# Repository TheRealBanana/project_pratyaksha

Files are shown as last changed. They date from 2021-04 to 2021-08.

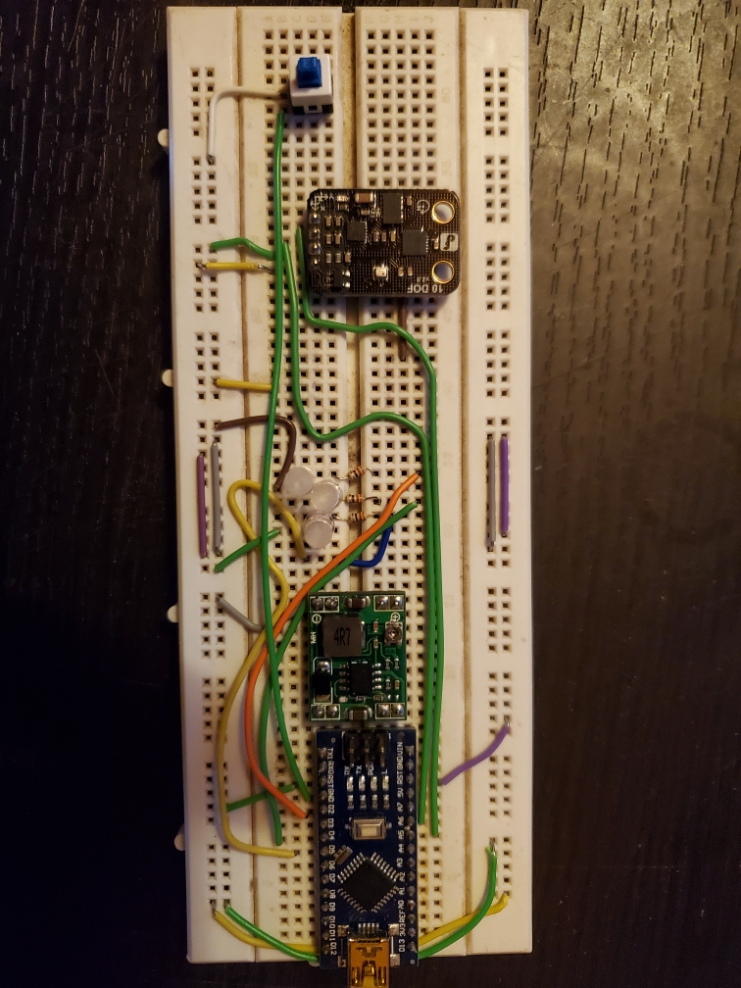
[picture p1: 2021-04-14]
testing_10dof_mems_sensor/breadboard_layout.jpeg

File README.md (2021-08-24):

# Project Pratyaksha
 Extra sensory perception via tactile stimulation

I was inspired by biohackers who have changed the sensory inputs their brains were receiving, showing that the brain can adapt quite well. Bicycles that turn the opposite way of the handlebars, glasses that enable you to see backwards, magnets under the finger to detect EM fields, and more. I wondered what it would be like to add some extra sense. How quickly would the brain learn to use the new information or would it just ignore the data as noise? 

The first idea I had was a simple navigation aid. A belt with 6 vibrating motors around the circumference that always vibrates in the direction of north, adding magnetoreception to our senses. There are many practical applications from helping seeing impaired individuals to a navigation aid for hikers. There's also no constraint as to the source of data being input. We could attach a software defined radio and instead buzz in the direction of certain radio signals. You could have a drone with object recognition inputting data as to the relative location of other people around you. Such a system would give an individual a real-life "spidy-sense".

It will be an interesting experiement. As of the creation of the repo its been under development for a little while (approx around the start of SensorMonitor repo) and I decided to track the progress on github.

--

May 2021 update

Here's what the first complete prototype system looks like. The belt is made from velcro material with the "buckles" self-designed and printed. Each "buckle" has a small 10mm diameter DC cellphone vibration motor glued into a matching recess. The leads from all 6 motors and a ground wire are routed out each end of the belt in 3-wire and 4-wire bundles. Each wire bundle is terminated at its end with a 6-pin header block. The main brainbox contains a custom subboard and a small atmel atmega2560 based prototyping board. The belt plugs into the subboard while the atmel controls everything. The magnetic heading data is taken from the SEN0140 10 degree-of-freedom sensor package. The magnetic heading data is corrected for tilt using the on-board IMU. The placement of the SEN0140 sensor is still undecided so its on a long lead. 

pratyaksha_belt-fullsystem_prototype_1

Aug 2021 update
Turns out not knowing anything about designing circuit boards came back to bite me. My current design has overcurrent issues burning traces out. I needed to add a current limiting resistor to the motor outputs (not sure why I didnt) and maybe thicker traces. Taking a break from the project for a while to concentrate on a laser projector I'm trying to design.

A pic of the v2 board that didn't work right:
pratyaksha_belt-pcb-v2

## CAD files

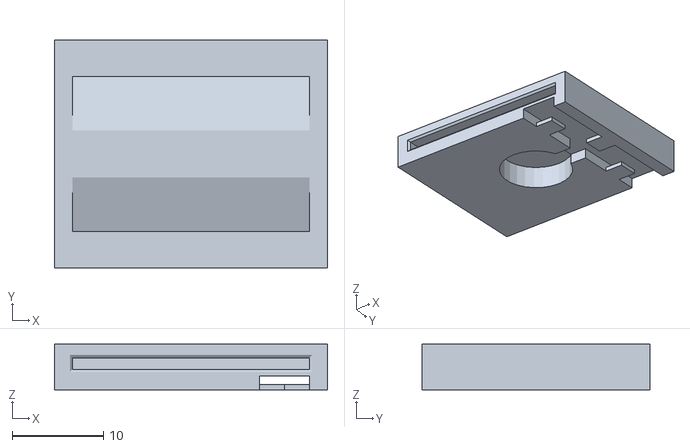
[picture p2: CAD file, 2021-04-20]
CAD Files/body_interface_pad/body_interface_pad_type2_mk1.stl
30.0 x 25.0 x 5.00

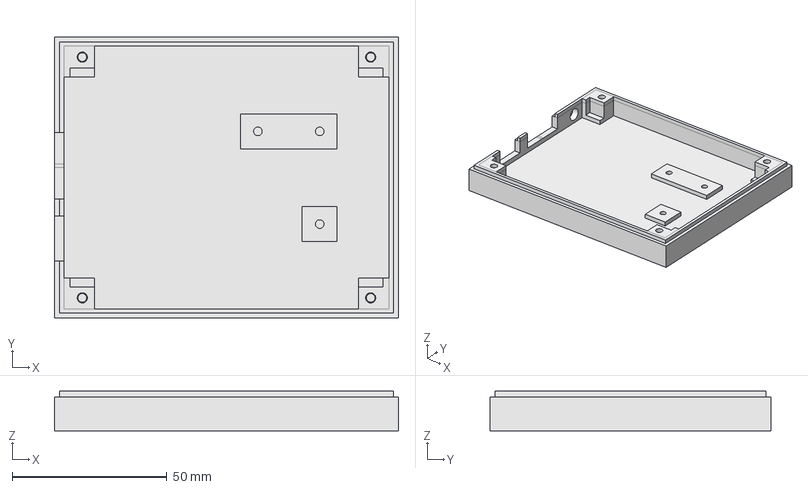
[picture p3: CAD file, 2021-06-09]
CAD Files/brainbox/brainbox_type2.FCStd
111.3 x 91.0 x 12.8 mm

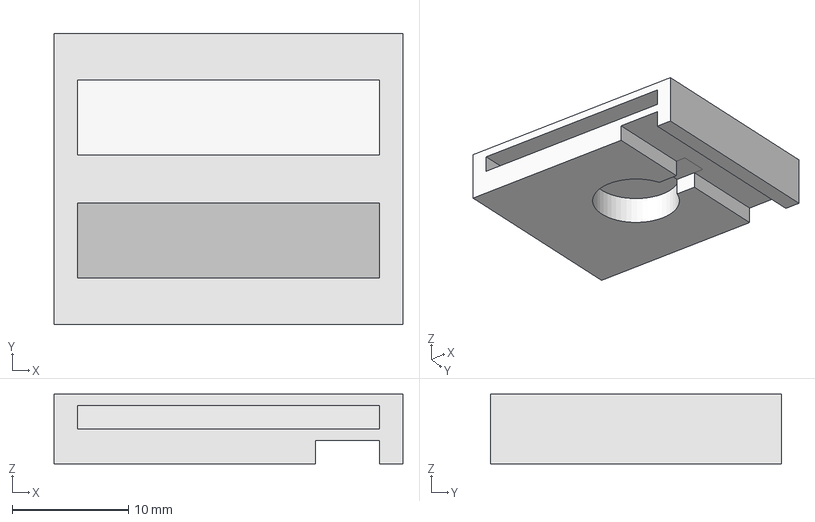
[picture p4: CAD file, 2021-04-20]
CAD Files/body_interface_pad/body_interface_pad_type2.FCStd
30.0 x 25.0 x 6.00 mm

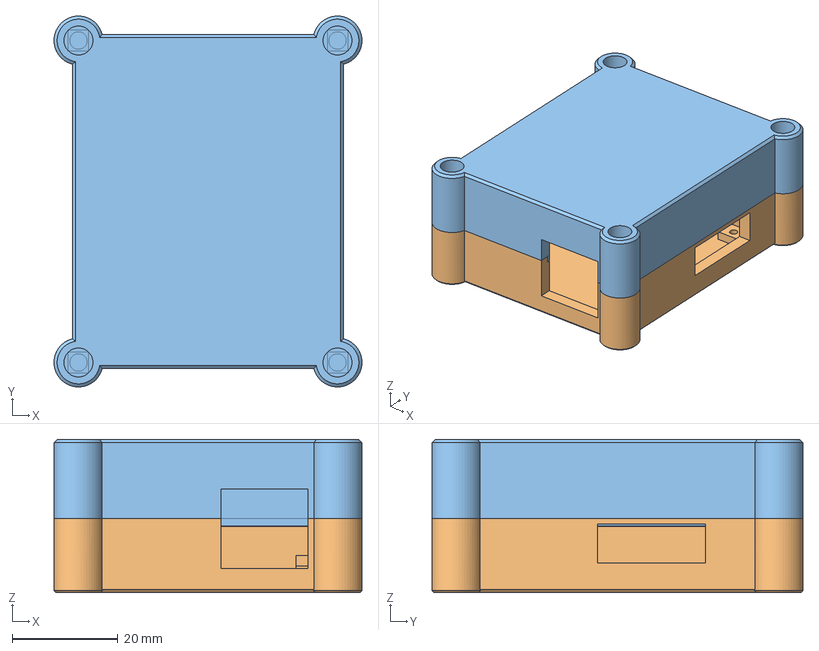
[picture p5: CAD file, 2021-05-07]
CAD Files/brainbox/brainbox_type1.FCStd
58.4 x 70.3 x 29.0 mm
Mini Atmega2560 mockup
Case - sub-board side
Case - atmega side

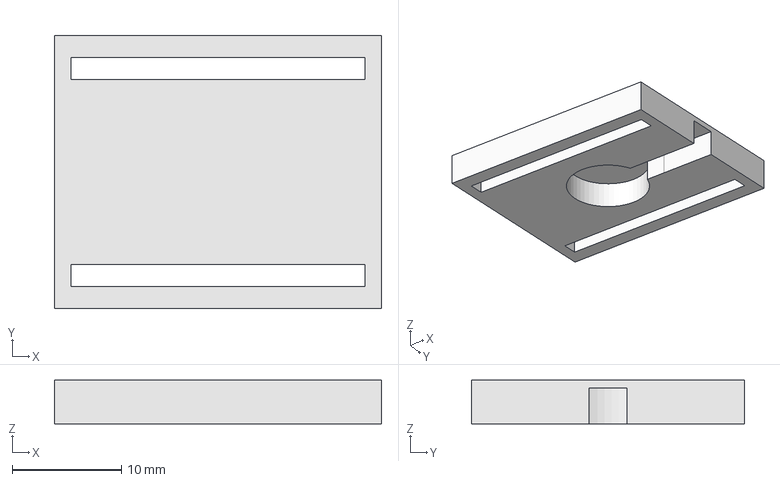
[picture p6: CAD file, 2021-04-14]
CAD Files/body_interface_pad/body_interface_pad_type1.FCStd
30.0 x 25.0 x 4.00 mm

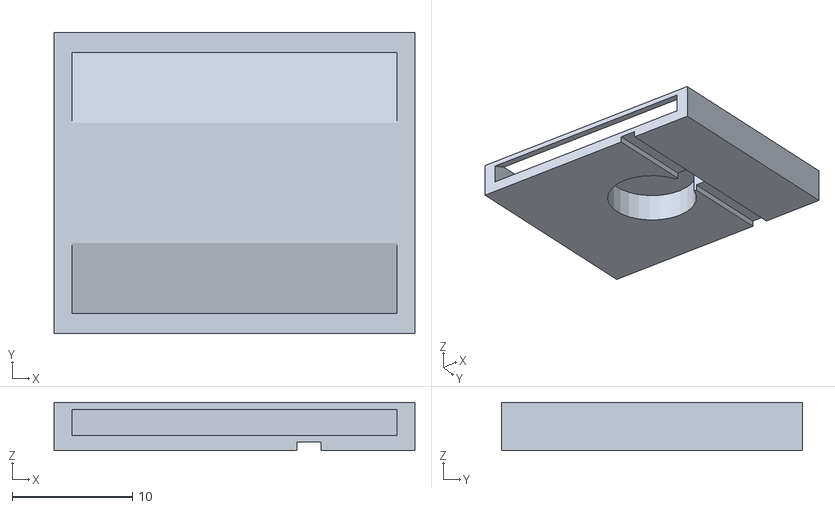
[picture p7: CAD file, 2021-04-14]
CAD Files/body_interface_pad/body_interface_pad_type1_mk1.stl
30.0 x 25.0 x 4.00

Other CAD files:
CAD Files/body_interface_pad/body_interface_pad_type2_mk2.stl
CAD Files/body_interface_pad/body_interface_pad_type1_mk4.stl
CAD Files/body_interface_pad/body_interface_pad_type1_mk3.stl
CAD Files/body_interface_pad/body_interface_pad_type1_mk2.stl
CAD Files/body_interface_pad/body_interface_pad_type1.3mf

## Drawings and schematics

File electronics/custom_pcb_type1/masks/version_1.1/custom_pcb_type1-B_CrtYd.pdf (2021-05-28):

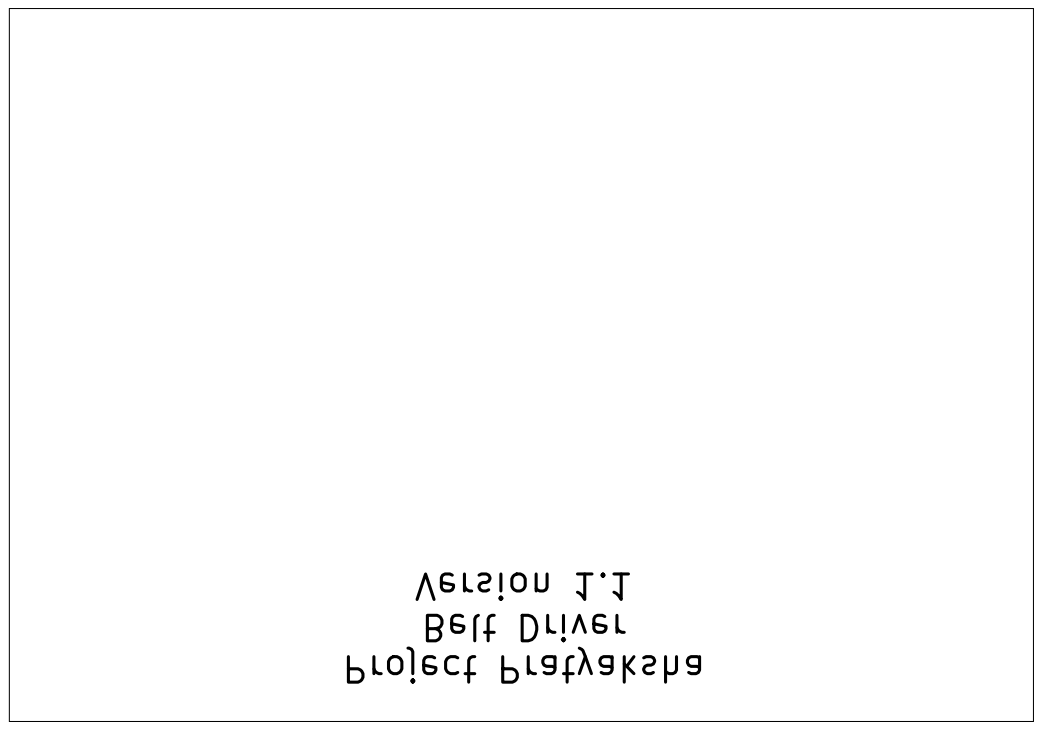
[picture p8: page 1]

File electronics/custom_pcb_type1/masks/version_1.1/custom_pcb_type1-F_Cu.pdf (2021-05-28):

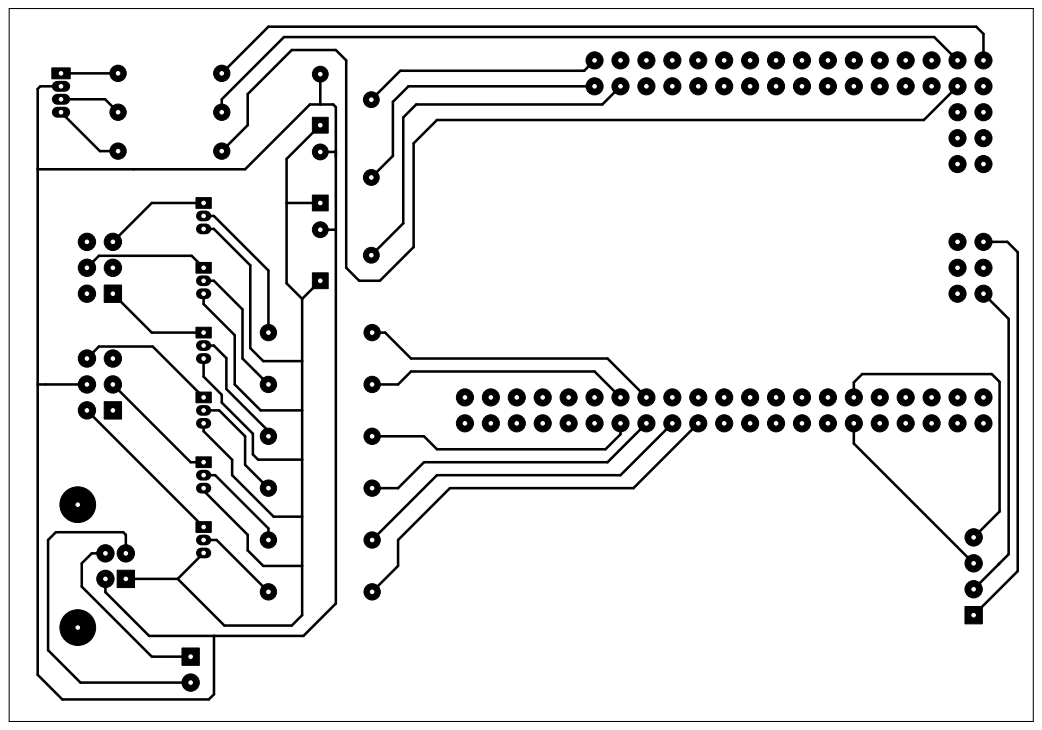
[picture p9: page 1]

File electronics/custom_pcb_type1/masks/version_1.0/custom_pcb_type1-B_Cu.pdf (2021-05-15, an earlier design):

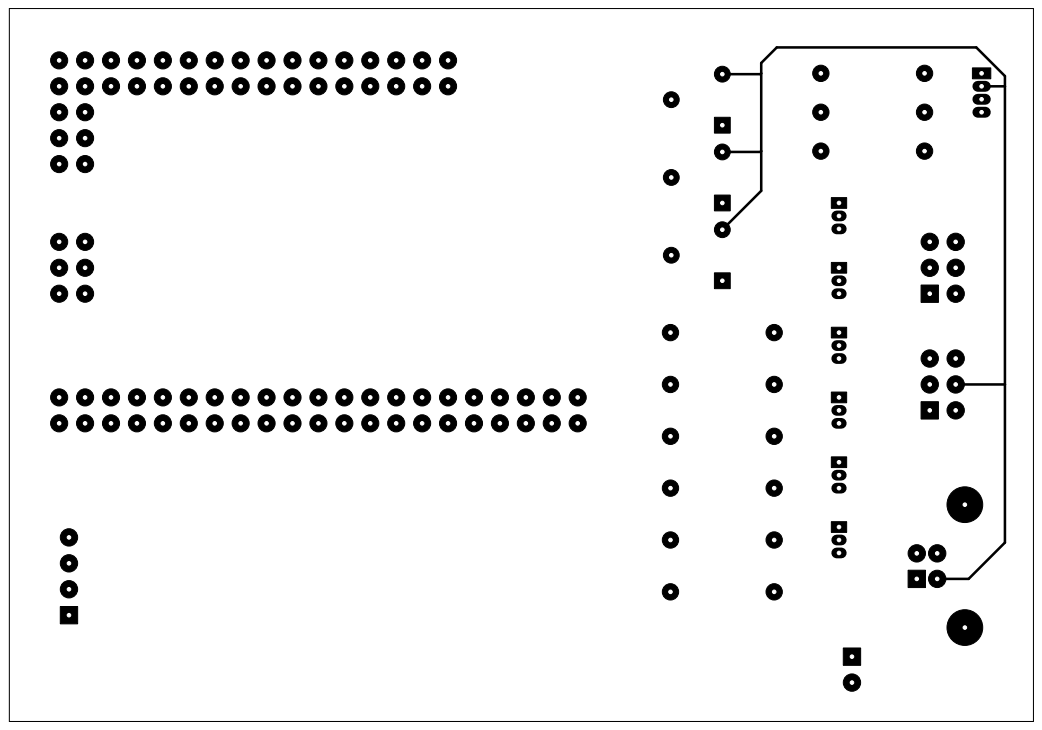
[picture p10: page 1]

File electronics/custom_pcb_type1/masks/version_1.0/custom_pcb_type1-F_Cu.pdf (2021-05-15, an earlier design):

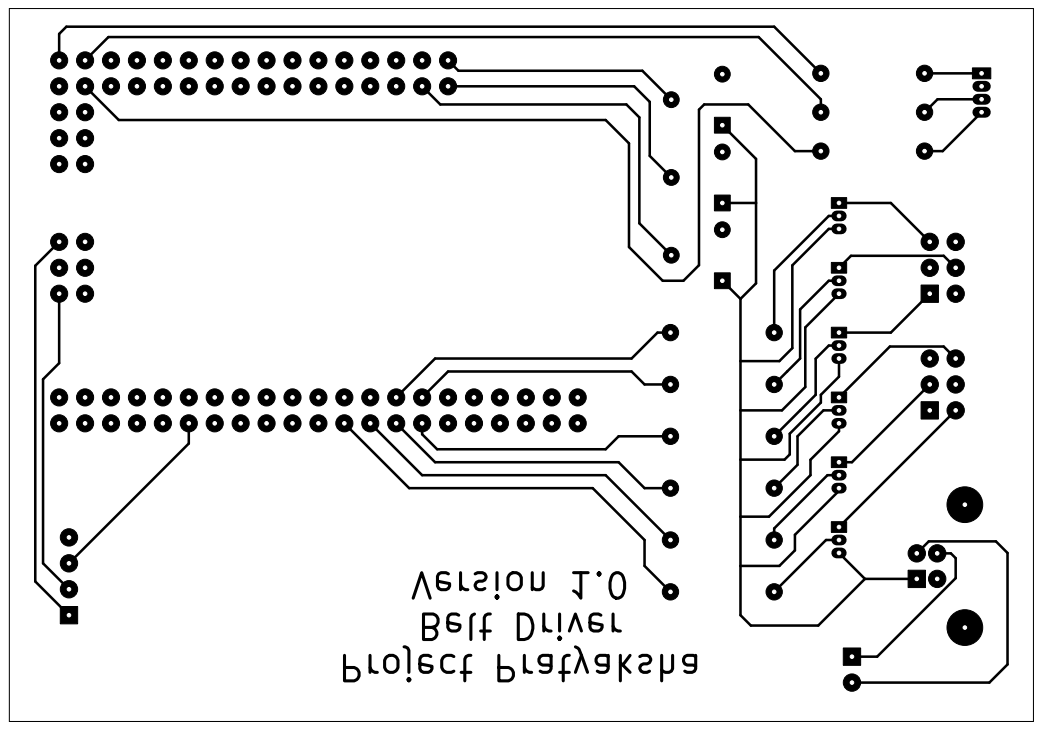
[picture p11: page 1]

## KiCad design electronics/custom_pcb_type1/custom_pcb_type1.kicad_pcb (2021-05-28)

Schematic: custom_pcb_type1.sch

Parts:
D1: LED_RGBC; LED_D5.0mm-4_RGB
J1: BELT_CONN_1; PinHeader_2x03_P2.54mm_Horizontal
J2: BELT_CONN_2; PinHeader_2x03_P2.54mm_Horizontal
J3: SEN0140; PinSocket_1x04_P2.54mm_Vertical
J4: USB_B; USB_B_OST_USB-B1HSxx_Horizontal
J5: JMPR_TO_ATMEGA; PinHeader_1x02_P2.54mm_Horizontal
Q1, Q2, Q3, Q4, Q5, Q6: 2N2222; TO-92_Inline
R1, R2, R3: 330; R_Axial_DIN0207_L6.3mm_D2.5mm_P10.16mm_Horizontal
R4, R5, R6, R7, R8, R9: 1.8K; R_Axial_DIN0207_L6.3mm_D2.5mm_P10.16mm_Horizontal
RV1, RV2, RV3: 10K; Potentiometer_Runtron_RM-065_Vertical
SW1: RST_SW; SW_PUSH_6mm
U1: MEGA_PRO_EMBED_CH340G___ATMEGA2560; _ATMEGA2560; PARTREV 12/May/2017

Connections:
+5V: J4.1 (VBUS), Q1.3 (C), Q2.3 (C), Q3.3 (C), Q4.3 (C), Q5.3 (C), Q6.3 (C), RV1.1, RV2.1, RV3.1
GND: D1.2 (K), J2.4, J4.4 (GND), RV1.3, RV2.3, RV3.3, SW1.1
unnamed: D1.1 (RA), R2.2
unnamed: D1.3 (GA), R3.2
unnamed: D1.4 (BA), R1.2
unnamed: J1.1, Q1.1 (E)
unnamed: J1.4, Q2.1 (E)
unnamed: J1.5, Q3.1 (E)
unnamed: J2.2, Q4.1 (E)
unnamed: J2.3, Q5.1 (E)
unnamed: J2.6, Q6.1 (E)
unnamed: J3.1, U1.5V_1 (5V), U1.5V_2 (5V), U1.5V_3 (5V)
unnamed: J3.2, U1.GND_1 (GND), U1.GND_2 (GND), U1.GND_3 (GND)
unnamed: J3.3, U1.D21
unnamed: J3.4, U1.D20
unnamed: J4.2 (D-), J5.2
unnamed: J4.3 (D+), J5.1
unnamed: Q1.2 (B), R4.1
unnamed: Q2.2 (B), R5.1
unnamed: Q3.2 (B), R6.1
unnamed: Q4.2 (B), R7.1
unnamed: Q5.2 (B), R8.1
unnamed: Q6.2 (B), R9.1
unnamed: R1.1, U1.D45
unnamed: R2.1, U1.D46
unnamed: R3.1, U1.D44
unnamed: R4.2, U1.D4
unnamed: R5.2, U1.D2
unnamed: R6.2, U1.D3
unnamed: R7.2, U1.D5
unnamed: R8.2, U1.D7
unnamed: R9.2, U1.D9
unnamed: RV1.2, U1.A0
unnamed: RV2.2, U1.A1
unnamed: RV3.2, U1.A3
unnamed: SW1.2, U1.RST
unnamed: U1.3V3_1 (3V3), U1.3V3_2 (3V3)
unnamed: U1.VIN_1 (VIN), U1.VIN_2 (VIN)

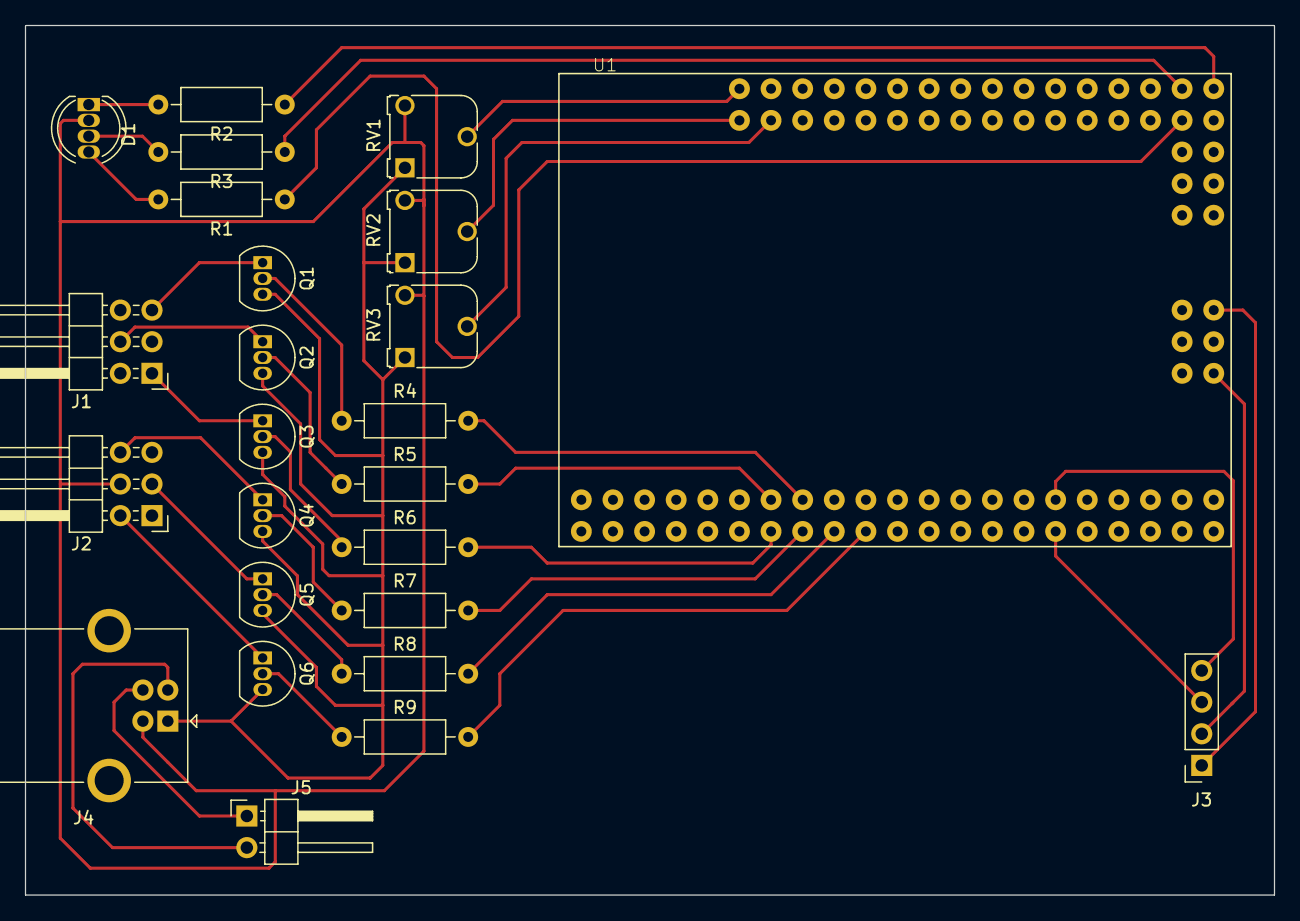
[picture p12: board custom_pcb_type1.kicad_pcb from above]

Board: 2 copper layers, 100.3 x 69.8 mm, 25 parts (0 on the bottom side), 37 nets.

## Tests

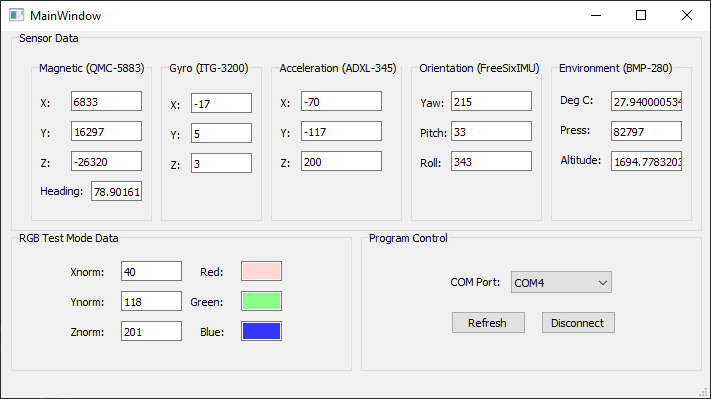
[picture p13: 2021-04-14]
testing_10dof_mems_sensor/SensorMonitor_V1.png

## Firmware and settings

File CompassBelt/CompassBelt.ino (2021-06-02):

// Ok here we go, the culmination of all the small test programs.
#include <Wire.h>
#include <Math.h>
#include <DFRobot_QMC5883.h>
#include <FreeSixIMU.h>
#include <ArduinoQueue.h>

int Rpin = 46;
int Gpin = 44;
int Bpin = 45;



//IMU sensor data
struct ID {
  long accelx;
  long accely;
  long accelz;
  long gyrox;
  long gyroy;
  long gyroz;
  long yaw;
  long pitch;
  long roll;
};
//magnetic sensor data
struct MD {
  long magx;
  long magy;
  long magz;
  float magh;
  long rgbxnorm;
  long rgbynorm;
  long rgbznorm;
};
DFRobot_QMC5883 compass;
FreeSixIMU sixDOF = FreeSixIMU();
float angles[3]; // yaw pitch roll
int accval[3]; //Raw acc
float gyroval[3]; // Raw gyro
float declinationAngle = (11 + (37.0 / 60.0)) / (180 / PI);
//Range values for sensor
//The min constrain here is based on the ambient magnetic field at my location to get rid of some noise
//It really needs proper compensation but this works for now
int SENSOR_MIN = -32767;
int AMBIENT_MIN = 2000;
int SENSOR_MAX = 32767;
bool ENABLE_AMBIENT_MIN_CAL = false; //Try and figure out a noise floor at startup. Overrides AMBIENT_MIN.
bool ENABLE_MAG_CALIBRATION = true;
Vector mag = {0,0,0};
int compass_angle = 0;
int raw_compass_angle = 0;
//Magnetic calibration using this page as a guide:
// https://github.com/kriswiner/MPU6050/wiki/Simple-and-Effective-Magnetometer-Calibration
int mag_bias[3] = {0,0,0};
float mag_scale[3] = {0.0f,0.0f,0.0f};
int mag_max[3] = {-32767,-32767,-32767};
int mag_min[3] = {32767,32767,32767};
int mag_temp[3] = {0,0,0};
int zmag_polarity_bias = 0;
int mag_cal_duration = 15; //In seconds
int ZERO_WAIT_DELAY = 6; //How long do we wait before we take the zero-heading reading?
int mag_heading_offset = 0; // How far off is the sensor's current orientation from true north? Cant perfectly aligning the sensor's north with our body so why try.


const int NUM_MOTORS = 6;
int MOTOR_ANGLE = (360/NUM_MOTORS); //Number of degrees between motors when mapped to a circle
// getOutputPinsFromAngle() returns index 0 when you give an angle of 0 or 360 (north). So straight forward should be index0 which should be the belly buzzer which should be the first motor on the belt (red motor). 
int MOTORS[NUM_MOTORS] = {4, 2, 3, 5, 7, 9,}; //Pins are not sequential anymore since the custom PCB layout
int MOTOR_PWM_MIN = 100; //Min value before the motor starts to move. Its actually 60 but you dont feel much until 70.
int MOTOR_PWM_MAX = 255; //Max range of our PWM output
int INTENSITY_ADJUST_POT_PIN = A0; // For changing the intensity of vibrations (PWM MAX)
int FILTER_SIZE_POT_PIN = A1; // For changing the size of the heading filter buffer
int MANUAL_HEADING_OFFSET_POT = A3; // For manually adjusting the heading offset value
float PWM_DELAY = 1.0; //Trying to get rid of weird flickering now

struct MotorOutput {
  int motor1_pin;
  int motor1_pwm;
  int motor2_pin;
  int motor2_pwm;
};

int motorpin_index;
int pot_value = 0;
int pot_angle = 0;
float pot_percent = 0.0f;

//My first idea for trying to smooth out the magnetic data
//Take the average heading over the last buffer_size readings (rolling average).
bool ENABLE_FILTERING = true;
int buffer_size = 25;
double sinheading = 0.0;
double cosheading = 0.0;
ArduinoQueue<double> sin_heading_buffer(buffer_size);
ArduinoQueue<double> cos_heading_buffer(buffer_size);
double sin_heading_buffer_rolling_sum = 0;
double cos_heading_buffer_rolling_sum = 0;
double atan_angle = 0;

//Calibrate our magnetometer for dur seconds
void magcal(int dur) {  
  //Turn on red LED to indicate we are calibrating and give two long pulses of the belt
  analogWrite(Rpin, 255);
  beltPulseIndicator(2, false);
  //Calibrate for dur seconds
  for (int t=0; t<dur*10; t++) {
    //Figure out the min and max of our sensor on all three axis
    mag = compass.readRaw();
    mag_temp[0] = mag.XAxis;
    mag_temp[1] = mag.YAxis;
    mag_temp[2] = mag.ZAxis;
    for (int j=0; j<3; j++) {
       if (mag_temp[j] > mag_max[j]) mag_max[j] = mag_temp[j];
       if (mag_temp[j] < mag_min[j]) mag_min[j] = mag_temp[j];
    } 
    delay(100);
  }
  //Calculate the bias and scaling factors
  //To use these correction values we subtract the bias factor and multiply by the scale factor
  mag_bias[0] = (mag_max[0] + mag_min[0])/2;
  mag_bias[1] = (mag_max[1] + mag_min[1])/2;
  mag_bias[2] = (mag_max[2] + mag_min[2])/2;
  int mag_scale_tmp[3] = {
    (mag_max[0] - mag_min[0])/2,
    (mag_max[1] - mag_min[1])/2,
    (mag_max[2] - mag_min[2])/2
  };
  float avg_rad = (mag_scale_tmp[0] + mag_scale_tmp[1] + mag_scale_tmp[2]) / 3.0f;
  mag_scale[0] = avg_rad/((float)mag_scale_tmp[0]);
  mag_scale[1] = avg_rad/((float)mag_scale_tmp[1]);
  mag_scale[2] = avg_rad/((float)mag_scale_tmp[2]);
  //Try and figure out a dynamic noise floor
  //Currently we just ignore anything below 2000 but maybe we can fine tune that at runtime
  //Maybe try just using the largest value we find in our min/max cal?
  //int m = max(abs(mag_min[0]), abs(mag_min[1]));
  //m = max(m, abs(mag_min[2]));
  //m = max(m, mag_max[0]);
  //m = max(m, mag_max[1]);
  //m = max(m, mag_max[2]);
  //Or maybe add up all the mins and maxes and take the average?
  int m = (abs(mag_min[0]) + abs(mag_min[1]) + abs(mag_min[2]) + mag_max[0] + mag_max[1] + mag_max[2])/6;
  if (ENABLE_AMBIENT_MIN_CAL) AMBIENT_MIN = m;
  //Indicate we are checking zero/aligning north pole with blue light and two fast pulses
  analogWrite(Bpin, 255);
  beltPulseIndicator(3, false);
  delay(ZERO_WAIT_DELAY*1000);
  setCompassOffset();
  mag = compass.readRaw();
  zmag_polarity_bias = mag.ZAxis;
  //Indicate we are done calibrating 
  analogWrite(Rpin, 0);
  analogWrite(Bpin, 0);
  delay(500);
  beltPulseIndicator(2, false);
  rgbflash(Rpin, 1);
  rgbflash(Gpin, 1);
  rgbflash(Bpin, 1);
}

Vector applymagcal(Vector mag) {
  if (!ENABLE_MAG_CALIBRATION) return mag;
  Vector out = mag;
  //Add our bias factor to recenter our data to 0
  out.XAxis = out.XAxis - mag_bias[0];
  out.YAxis = out.YAxis - mag_bias[1];
  out.ZAxis = out.ZAxis - mag_bias[2];
  //And multiply by the scaling factor to align the min/max range
  out.XAxis = mag.XAxis * mag_scale[0];
  out.YAxis = mag.YAxis * mag_scale[1];
  out.ZAxis = mag.ZAxis * mag_scale[2];
  
  return out;
}

Vector correctHeadingWithIMU(Vector mag, struct ID * imudata) {
  Vector out = mag;
  
  //Correcting heading data by applying a rotation to align the different frames of reference
  //Using MTD-0801_1_0_Calculating_Heading_Elevation_Bank_Angle.pdf as a reference guide
  //Convert to radians first
  float pitch = imudata->pitch * PI/180.0f; //Alpha
  float roll = imudata->roll * PI/180.0f;   //Beta
  //float pitch = atan2(imudata->accelx, imudata->accelz);
  //float roll = atan2(imudata->accely, imudata->accelz);
  //We only need the X/Y data to calculate heading so we dont need to rotate the Gamma angle
  out.XAxis = mag.XAxis*cos(pitch) + mag.YAxis*sin(roll)*sin(pitch) - mag.ZAxis*cos(roll)*sin(pitch); //Might need to subtract Z
  out.YAxis = mag.YAxis*cos(roll) - mag.ZAxis*sin(roll);

  //Correct for hard and soft iron deposits
  out = applymagcal(out);
  
  //Now calculate heading using arctan(magx/magy) and convert to degrees
  float magh_c = atan2(out.YAxis, out.XAxis) + declinationAngle;
  if (magh_c < 0.0f) magh_c += 2*PI;
  if (magh_c >= 2*PI) magh_c -= 2*PI;
  magh_c = magh_c * 180/PI;
  out.HeadingDegress = magh_c;
  //Serial.println("MAGH/MAGH_C: " + (String)mag.HeadingDegress + "  |  " + (String)out.HeadingDegress);
  //Serial.println("P/R: " + (String)(pitch* 180/PI) + "/" + (String)imudata->pitch + "  |  " + (String)(roll* 180/PI) + "/" + (String)imudata->roll);

  return out;
}
//Having trouble using normal averaging when the angle is around 0/360
//Taking the sin and cosine of the current angle will give us a smooth periodic value so there shouldnt be any swapping issues anywhere
//Then we take the atan2 of the average of the sine/cosine values to get our filtered heading.
int getFilteredHeading(int newheading) {
  sinheading = sin(degToRads(newheading)); 
  cosheading = cos(degToRads(newheading)); 
  if (!sin_heading_buffer.isFull() or !cos_heading_buffer.isFull()) {
    sin_heading_buffer.enqueue(sinheading);
    sin_heading_buffer_rolling_sum += sinheading;
    cos_heading_buffer.enqueue(cosheading);
    cos_heading_buffer_rolling_sum += cosheading;
    Serial.println(" - notfull returning last heading");
    return newheading;
  }
  // Now that we have a full buffer we take the average of all values and then take the atan2 of that value and return it
  // Only two things that change are removing the oldest value and adding a new value
  sin_heading_buffer_rolling_sum -= sin_heading_buffer.dequeue();
  sin_heading_buffer.enqueue(sinheading);
  sin_heading_buffer_rolling_sum += sinheading;
  cos_heading_buffer_rolling_sum -= cos_heading_buffer.dequeue();
  cos_heading_buffer.enqueue(cosheading);
  cos_heading_buffer_rolling_sum += cosheading;
  atan_angle = radsToDeg(atan2(sin_heading_buffer_rolling_sum/buffer_size, cos_heading_buffer_rolling_sum/buffer_size));
  if (atan_angle < 0) atan_angle += 360; //shift the negative portion of our output to the right
  Serial.println(" - AVG HEADING: " + (String)atan_angle);
  return atan_angle; 
}
//Makes the math look cleaner and hopefully it doesnt drag performance down 
double degToRads(int angle_in_degrees) { return angle_in_degrees*PI/180; } 
int radsToDeg(double angle_in_rads) { return angle_in_rads * 180/PI; }

//This function will either be called at the end of magcal or on a button press.
void setCompassOffset() {
  //Need to get an accurate heading to set the offset so we need IMU data here
  struct ID imudata = getIMUData();
  raw_compass_angle = getCompassHeading(&imudata);
  if (raw_compass_angle <= 180) mag_heading_offset = -raw_compass_angle;
  else mag_heading_offset = 360-raw_compass_angle;
}

int getCompassHeading(struct ID *imudata) {
  struct MD returndata;
  
  mag = compass.readRaw();
  
  //Serial.println("heading: " + (String)mag.HeadingDegress);
  mag.XAxis = constrain(mag.XAxis, SENSOR_MIN, SENSOR_MAX);
  mag.YAxis = constrain(mag.YAxis, SENSOR_MIN, SENSOR_MAX);
  mag.ZAxis = constrain(mag.ZAxis, SENSOR_MIN, SENSOR_MAX);
  //Apply tilt compensation and our calibration factors to the magnetic data
  mag = correctHeadingWithIMU(mag, imudata);
  //Correct for alignment of sensor
  mag.HeadingDegress += mag_heading_offset;
  Serial.println(360-mag.HeadingDegress);
  return 360-mag.HeadingDegress;
};

struct ID getIMUData() {
  struct ID returndata;
  
  sixDOF.gyro.readGyro(gyroval);
  sixDOF.acc.readAccel(accval);
  //Sensor drift, especially for the yaw axis, is really bad for some reason with getAngles()
  //sixDOF.getAngles(angles); // These values are absolute values from 0-360
  sixDOF.getYawPitchRoll(angles); // This is the type of values we need, relative different in angle from rest.
  //sixDOF.getEuler(angles);
  returndata.accelx = accval[0];
  returndata.accely = accval[1];
  returndata.accelz = accval[2];
  returndata.gyrox = gyroval[0];
  returndata.gyroy = gyroval[1];
  returndata.gyroz = gyroval[2];
  returndata.yaw = angles[0];
  returndata.pitch = angles[1];
  returndata.roll = angles[2];

  return returndata;
}
// Instead of the visual indicator I'm going to use the belt to signal states
// Temporary until I can get v2 of the PCB designed and built, which will include the status LED.
void beltPulseIndicator(int count, bool fastmode) {
  for (int i=0; i<count; i++) {
    //I think index 3 is the motor on the belly of the belt
    //Maybe doing the 4 corners (F B L R) would be better? Less ambiguous since in normal operaton
    //the belt cant activate more than 2 motors at once. 
    analogWrite(MOTORS[0], 255);
    if (fastmode) delay(50);
    else delay(150);
    analogWrite(MOTORS[0], 0);
    delay(300);
  }  
}
void rgbflash(int pin, int num) {
  for (int i=0; i<num; i++) {
    analogWrite(pin, 255);
    delay(100);
    analogWrite(pin, 0);
    delay(100);
  }
}

void getOutputPinsFromAngle(int angle, struct MotorOutput *motorvals) {
  angle = constrain(angle, 0, 360);
  motorpin_index = angle/MOTOR_ANGLE;
//  if (motorpin_index < 0) motorpin_index = NUM_MOTORS - 1; //the frick is going on here?? I assume at some point previously we were subtracting from motorpin_index? dont think we need this anymore.
  else if (motorpin_index == NUM_MOTORS) motorpin_index = 0;
  motorvals->motor1_pin = MOTORS[motorpin_index];
  if (motorpin_index == NUM_MOTORS-1) motorvals->motor2_pin = MOTORS[0];
  else motorvals->motor2_pin = MOTORS[motorpin_index+1];
}

struct MotorOutput interpFromAngle(int angle, struct MotorOutput *motorvals){ 
  float ratio = 1.0 - ((float)(angle%MOTOR_ANGLE)/(float)MOTOR_ANGLE);
  motorvals->motor1_pwm = (int)(ratio * MOTOR_PWM_MAX);
  motorvals->motor2_pwm = MOTOR_PWM_MAX - motorvals->motor1_pwm;
}

void zeroPWMvals() { for (int i=0; i<NUM_MOTORS; i++) analogWrite(MOTORS[i], 0); }
void writeToMotors(struct MotorOutput *motorvals) {
  zeroPWMvals(); 
  //In testing I've found the motors don't start working until the PWM value reaches about 60
  //Because we are writing a zero first we don't have to worry about 60 being too low and motors never switching off
  analogWrite(motorvals->motor1_pin, map(motorvals->motor1_pwm, 0, 255, MOTOR_PWM_MIN, MOTOR_PWM_MAX)); 
  analogWrite(motorvals->motor2_pin, map(motorvals->motor2_pwm, 0, 255, MOTOR_PWM_MIN, MOTOR_PWM_MAX)); 
  delay(PWM_DELAY);
}


void setup() {
  analogWrite(Rpin, 0);
  analogWrite(Gpin, 0);
  analogWrite(Bpin, 0);
  Serial.begin(9600);
  // Loop through and set output mode on all MOTOR pins
  for (int i=0; i<6; i++) pinMode(MOTORS[i], OUTPUT);
  sixDOF.init(true);
  //Magnetometer init
  while (!compass.begin())
  {
    Serial.println("Could not find a valid 5883 sensor, check wiring!");
    delay(500);
  }
  if (ENABLE_MAG_CALIBRATION) magcal(mag_cal_duration);
  compass.setDeclinationAngle(declinationAngle);
}

void loop() {
  struct MotorOutput motor_outputs; //Should be destroyed and recreated each loop iteration, not leaking.
  
  // Map the pot output from 0-1023 to 0-360
  pot_value = analogRead(INTENSITY_ADJUST_POT_PIN);
  //MOTOR_PWM_MAX = map(pot_value, 0, 1023, 0, 255);  //TODO FIX ME IN HARDWARE!
  struct ID imudata = getIMUData();
  raw_compass_angle = getCompassHeading(&imudata);
  //smooth the value out
  if (ENABLE_FILTERING) compass_angle = getFilteredHeading(raw_compass_angle);
  else compass_angle = raw_compass_angle;
  //Get the output pins based on the angle
  getOutputPinsFromAngle(compass_angle, &motor_outputs);
  //Get the PWM values for those motors, interpolated between the two
  interpFromAngle(compass_angle, &motor_outputs);
  //We should now have everything we need to output the correct PWM value to the correct pin
  writeToMotors(&motor_outputs);
}

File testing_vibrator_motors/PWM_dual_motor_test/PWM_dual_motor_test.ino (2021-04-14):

int MOTOR_PIN = 6; //Can also do PWM on this pin
int MOTOR_PIN_2 = 5;
int POT_PIN = A0; //Dont have to set to input to do analogRead()

struct motors {
  int m1 = 0;
  int m2 = 0;
};

int pot_value = 0;
float pot_percent = 0.0f;
int pwm_value = 0;
struct motors mvals;

void setup() {
  // put your setup code here, to run once:
  Serial.begin(9600);
  pinMode(MOTOR_PIN, OUTPUT);
  digitalWrite(POT_PIN, LOW);
}

struct motors interpolate(float ratio, int value){ 
  struct motors outvals;
  outvals.m1 = (int)(ratio * (float)value);
  outvals.m2 = value - outvals.m1;
  return outvals;
}

void loop() {
  
  // Figure out our delay based on the 1k potentiometer
  pot_value = analogRead(POT_PIN);
  mvals = interpolate((float)pot_value/1023.0, 255);
  Serial.print(mvals.m1);
  Serial.print(" | ");
  Serial.println(mvals.m2);
  //Serial.println(pot_value);
  //pwm_value = map(pot_value, 0, 1023, 40, 255);
  //Serial.println(pwm_value);
  analogWrite(MOTOR_PIN, mvals.m1);
  analogWrite(MOTOR_PIN, mvals.m2);
}

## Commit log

2021-04-14 Added ignore for subrepo
    https://github.com/TheRealBanana/SensorMonitor
    I dont know how to link a subfolder to another repo so ignoring for now.
2021-04-14 Updated wire channel cutout
    My original idea had the wires running under the belt but that bundle of wires is big enough to lift the pads away from our skin. New design is going to run the wires directly below the belt. May nee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
    [body_interface_pad_type1.FCStd, body_interface_pad_type1_mk4.stl]
2021-04-17 Bigly bugs
    Got the first hardware prototype of the belt finished (barely) but when I tested it out I got a ton of random vibrating all over the place. Nothing worked right lol. They say in the military that no plan survives first contact with the enemy. Well it seems no code (of mine) survives first contact with the hardware! In my defense these are classic C-lang bugs and I just dont work with C often enough.
    The very first (and probably the most severe) bug was that I was using the motorpin value as an index, which was very bad. I decided to just track the index in a variable but I'm thinking just as I type this that I could possibly just use a pointer instead, and then I could increment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
    [PWM_circular_motor_config_test.ino]
2021-04-18 Actual bug fix for real
    Last update was just a code review. Actually running the code on the hardware was still a hot mess. To get things sorted out I swapped the belt for 6 LEDs as an output and it made diagnosing the issue so much easier. First off, the fix for the motor array index was itself flawed with the very issue it was supposed to fix! Instead of setting the index at line 65 (67 now), I was setting the pin number. Doh! The check of the index to roll over if we got larger than the array size was also flawed, somehow forgetting the array is indexed from 0. I also had the ratios backwards for motor1 and motor2, so just doing a 1-ratio solved that easily. Finally the debug println show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
    [PWM_circular_motor_config_test.ino]
2021-04-19 Better PWM
    Forgot to mention in the last commit that I also changed the way the PWM values were being written because the motors were staying on after they were set to any PWM value. At first I decided to just delay after writing the PWM and then write a 0 to the 2 active motors. That worked but didn't produce a continuous output. New solution is to write a 0 first to all motors and then the PWM value and that provides a perfectly continuous and smooth output. At this point I think I got this test code working and now I can get the heading information sorted out.
    The only two issues left I can think of atm is that the 360 degree point is actually overshooting and landing on the first motor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
    [PWM_circular_motor_config_test.ino]
2021-04-20 Body interface pad changes
    Unfortunately the limitations of TPU in the printing setup I have means I can't bridge very long gaps without significant sag or even breakage (even at full 100% fan speed). That was why I had to route the straps straight through instead of internally on the type 1. I went with TPU originally because I thought it would be more comfortable than PETG. But the design changes forced by the properties of TPU I think mean the plastic versions would be more comfortable. So now we have a body interface pad type 2.
    Instead of straight through strap routing, its now routed internally. This gives us clean access to the bottom of the pad where the wiring can be routed. The ty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
    [body_interface_pad_type2.FCStd, body_interface_pad_type2_mk1.stl, body_interface_pad_type2_mk2.stl]
2021-04-21 Filtering heading
    Realized that I didn't need to add up every heading in the buffer every time I wanted a new average, I just had to keep a sum and subtract from it the oldest value in the buffer while adding the newest value. Kind of a poor-mans PID but it works reasonably well for what I need. Changing the value of buffer_size will affect how slowly the value changes. Current value of 25 seems to take the filter about a second to catch up to any massive heading changes. Will tune this further when real heading data is being input.
    [PWM_circular_motor_config_test.ino]
2021-04-21 Finishing touches before magnetic data
    Holy smokes, first time I've hooked up the belt hardware to the new code and ITS AMAZING! I can totally feel like theres a seemless transition between the nodes, exactly as hoped! Now It should just be simple as piping in the magnetic heading data. I'm still going to have to rework the maths a bit to clean up the tilt compensation but its mostly workable. If that fails I do have a BN-880 GPS module I can probably get clean data off of.
    [PWM_circular_motor_config_test.ino]
2021-04-21 Fully integrated stage 1
    I grafted the magnetic sensor parts of the SensorMonitor arduino code onto the circular PWM test file and this is what I got. The biggest issue right now is that the poor-mans PID works great until you get to 0/360 heading. Around there it goes bananas since the values are so wildly different. So looks like we either need no filtering, a better poor mans filter (somehow), or actually implement PID or parts of it. An even bigger problem is that the arduino freezes after a few seconds running so somewhere we messed up with memory management. With this massive mess of code its no wonder. I think I will probably have to just write this from scratch without grafting. Damn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
    [CompassBelt.ino]
2021-04-23 Changed test mode
    Instead of the pot controlling the angle of the output, it now controls the speed at which the output is cycled from 0-360. This mode allowed me to dial in certain parameters more easily, like the pwm value. This produces the smoothest output so far although you can feel small gaps every now and then.
    Still have the major crashing issue with the arduino. Even just outputting the heading without any parts of the motor program is crashing eventually, which the sensormonitor app never did (or I never experienced it). Not sure if its the hardware or what because the sensormonitor app ran on an arduino nano and this is running on a very old uno. I may switch over to an mega256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
    [PWM_circular_motor_config_test.ino]
2021-04-23 Works, using mega 2560 now
    I was hoping I wouldnt have to resort to the mega because of its size but so far everything is now working great. The excess of PWM pins is a nice thing to have as well since before we had used all 6. That allowed me to add back in the status indicator LEDs.
    One big change was to the order of the motor pins. In the old order everything was backwards with north on your back. I just moved everything over 3 slots and now its aligned properly. Besides that its the same code, just now it doesnt crash. I still need to solve the power issue by just not driving the motors directly from the pins. Will look into if I can get away with some simple npn transistors, been a whi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
    [CompassBelt.ino]
2021-04-24 Testing a very basic fix for filtering
    I wanted to go the full PID route but decided to try and just transform the angle we were getting with a period function. I settled on tan/atan2 since it seemed like the only way to get a continuous output in the range I needed. I had to track both the sine and cosine of our heading angle though so thats not great. So although the maths are a little brute-forced, it does actually work. It only goes haywire when there are massive shifts in the angle, like +- 90 degrees but the values eventually settle again.
    [PWM_circular_motor_config_test.ino]
2021-04-24 Atan2 averaged Filtering
    Applied the same solution to the belt code and all seems to be working fine. Ran into another crash however. It seems I forgot to hook up the ground all the motors were using but somehow they were still running by grounding through the other motors's power pins when they arent in use. A few diodes would fix that. Anyway I discovered the problem and added the ground and then the crashes started. So it does seem like a power issue of some sort. At least the filtering works though.
    [CompassBelt.ino]
2021-04-24 Enable PWM max tuning
    Added in the ability to tune the max output of the motors via the potentiometer at A0.
2021-04-25 Fixed bug in heading filter
    Fixed a major bug where the cosine parts of the filter were actually being fed sine data. It kind of sort of actually worked even with the bug but the weird issues I was having are seemingly just this bit of code. Moved the setup() function to an easier to find spot. I should really standardize on a single way to order functions.
    Next up for the project is miniaturizing this whole thing so I can start walking around with it full time. I bought an $11 "AITRIP Mega 2560 Pro Embed". Its a tiny (3.8cm x 5.5cm) atmega2560 board with full pinout. This thing is going to be sweet and small, should fit really nice in a sleek case I can have on the belt or in my pocket. Th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
    [CompassBelt.ino]
2021-05-01 First hardware prototype
    Finished soldering up the first hardware prototype and it seems like it actually worked on the first try! That like almost never happens lol, I usually end up resolding one or two things. I made doubly sure my breadboard circuit worked and then just copied it all over. I didn't include the potentiometer so Its been disabled in the code for now. Also I didn't solder the sensor onto anything yet as I'm still undecided where to locate it.
    The first instinct is just to put the sensor on the same board as everything else and jam it in our pocket. Thing is, our tilt compensation aint the greatest so the random orientation in our pocket probably won't be great. The second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
    [CompassBelt.ino]
2021-05-06 Added corrections for sensor heading misalignment
    First trials with the prototype hardware I found immediately that I had to have the sensor perfectly aligned with my body for the whole thing to work properly. This correction offset will fix that. At the end of magcal or maybe on button press (or both?) we will give the wearer a few seconds to align their body to north using another compass. We then take the difference between that heading and our sensor's heading and get an offset we can add or subtract. This should allow the sensor to be placed in an arbitrary orientation and still function properly. Im still a bit worried that at extreme tilt angles my questionable tilt compensation maths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
    [CompassBelt.ino]
2021-05-06 Brainbox CAD
    Starting work on the brainbox to hold everything and Ive got the two boards basically mocked up. Now will build the case around it.
    [brainbox_type1.FCStd]
2021-05-07 Sub-board brainbox half started
    Got the side of the case holding the sub board basically designed. Got most of the way complete when I realized there was no space for case screw holes so I had to improvise with the bulbs on the corners. I also think I may need to add a removable brace behind the USB port since its not mechanically fixed to the PCB.
    [brainbox_type1.FCStd]
2021-05-07 Case v1 finished
    got the very basics finished, its a couple pieces of plastic that should contain both PCBs and their wires nicely. It has no provisions for buttons, status leds, or anything like that. This is bare bones. I couldnt figure out what the case would look like in my head so it was hard to preplan things like buttons and LED locations. Now that I have this case finished I can start to think about where I want to add those extra bits. Next case design will be from scratch, learning from the issues that come up with this version.
    Not near a 3D printer atm so will have to wait a day before I can print this out.
    [brainbox_type1.FCStd]
2021-05-10 Software adaptations to hardware limitations
    Decided just to leave the current hardware alone and use it for a while. To that end instead of a status LED I decided to use vibration patterns instead. 2 slow buzzes means calibration has started, 2 fast buzzes indicates we are about to take the compass offset heading (so we need to face north). Currently it waits 5 seconds before it takes the offset reading. Finally 3 slow buzzes means everything is ready to go.
    [CompassBelt.ino]
2021-05-10 Update README.md
    Added further details about the device construction and a picture of the final prototype system.
2021-05-10 fat fingered it
    yeap
2021-05-10 Actually set compass offset
    Forgot to actually set the compass offset. Also fixed the buzzing indicator to actually work instead of blurring all individual buzzes into one long buzz.
    [CompassBelt.ino]
2021-05-13 Starting work on custom PCB
    I'm tired of making PCBs by hand using crappy protoboard and the constraints it brings. I have a laser printer and a drill already so with just some ferric chloride and raw PCB blanks I should be abl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
    Also added 2 new potentiometers to the circuit so I had to add new references in the arduino code. The variable names are now perfectly descriptive.
    [custom_pcb_type1.kicad_pcb, custom_pcb_type1.sch]
2021-05-13 Added USB connector
    I'm pulling power from a secondary USB port on my prototype board and I plan to do the same here. The +5V from the USB port is used directly by everything and is passed to the atmega through its usb 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
    [custom_pcb_type1.sch]
2021-05-13 Physical PCB start
    Sort of got a start on the physical PCB layout. Its hard to lay things out in ways that don't overlap with other traces on a single layer. I got most of everything connected up and I think what I hav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
    [custom_pcb_type1.kicad_pcb, custom_pcb_type1.sch]
2021-05-13 Better PCB routing
    Before I started doing the back side routing I decided to try rerouting things for more traces on the top layer. I ended up changing the pinout to use even numbered pins 2-12 backwards (i.e. first mo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
    [custom_pcb_type1.kicad_pcb, custom_pcb_type1.sch]
2021-05-14 PCB version 1.0
    Ok I've finished laying everything out. In the end I was successful in laying out the data and power traces on top and only have ground traces on the bottom. I've generated the reversed masks that are ready for laser printing. Now I'm realizing that transferring the mask to the PCB is going to be a slightly involved task. I've settled on the rolling pin + hotplate method since I don't want to build a jig to hold an iron upside down and I don't want to spend the time modifying a cheap ebay laminator to work with PCBs. Going forward I may switch to a photoetching process instead since that doesn't require heat+pressure. Although it requires a few more chemicals it seems like a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
    [custom_pcb_type1.kicad_pcb, custom_pcb_type1.sch]
2021-05-14 Cleaned up traces
    Looking at the mask I saw a couple spots where It was questionable if it would etch properly. I just separated out the traces the best I could. I'm wondering if I could remove the unused pins of the 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
    [custom_pcb_type1.kicad_pcb]
2021-05-15 Size matters
    Welp Got all the way to putting the transfer paper onto the PCB when I found out that my raw PCBs are kinda small. 70mm x 100mm - which is a lot smaller than the current footprint of like 90mm x 120mm. So LOTS of rearranging things and reassigning pins. I think the end result is a far better board than the previous one so It was well worth the effort. I made sure to not route any traces too close to the edge, other traces, or other pin holes. Trying to give the toner transfer the best possible chance of at least not bridging stuff.
    [custom_pcb_type1.kicad_pcb, custom_pcb_type1.sch]
2021-05-15 Forgot some text
    Forgot the text I added to identify the board and version. It should be nicely visible even after all components are on the board.
    [custom_pcb_type1.kicad_pcb]
2021-05-24 Moved some traces
    Finally got around to trying to make the PCB and it actually went fairly well. My first try had something mostly workable, just a few traces that bridged here and there. Probably just improper techni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
    With this first board I was only interested in the processes and not the final product so I didnt attempt to protect the back from etching. I realized theres only like 4 or 5 ground connections anywa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
    [custom_pcb_type1.kicad_pcb]
2021-05-24 D+ trace move
    D+ ran a bit close to the GND pad of the USB connector. It didnt bridge in my first PCB but Its easy enough to move a little and avoid any problems in the future.
    [custom_pcb_type1.kicad_pcb]
2021-05-28 Rerouting to be single-sided
    Since I can't plate my through-holes, any connections on the opposite side of the board had to be soldered too. The problem there is that the components are in the way so you can't solder. Because of this I decided to route all the ground traces on the top. At first I had planned to just put some through-hole vias that were away from components to fix that soldering issue. Then I realized I could route them all on the top no problem, so I went that way. The traces are really the "bottom" now and the top is where the components are with the project name/version mask.
    Also didn't realize I forgot to connect one of the pins for the SEN0140 board. I guess I deleted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
    [custom_pcb_type1.kicad_pcb]
2021-06-02 Adjustments for new PCB design
    The final custom PCB changed some of the pins to make trace routing easier. In addition to updating those pin numbers, I switched the order of motors in MOTORS[] to be sequential instead of the right-shifted order currently (with the red motor 5 at index 3). Technically, we want angle 0 and 360 (north) to vibrate our belly motor. The getOutputPinsFromAngle() function will return index 0 when input with angle 0/360 so it makes sense to put red motor at index 0. I can't remember why I changed it in the first place. Also theres a line in getOutputPinsFromAngle that I can't fathom atm. I'm pretty sure its from some old version of a completely different program so I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
    [CompassBelt.ino, PWM_circular_motor_config_test.ino]
2021-06-03 Brainbox type2
    Start of work for the type2 brainbox that is for our custom PCB. Atm I only have the board mockup and a support for the SEN0140 board.
    [brainbox_type2.FCStd]
2021-06-09 Case bottom finished
    Finished working on the bottom part of the case. As soon as it finished printing and the fitment is good I will design the top half.
    [brainbox_type2.FCStd]
2021-08-24 Updated readme and changed to public
    Taking a break from this project for a little while so I figured I would make it public. Most of the work is done. The code is a little shaky in terms of stability (and I'm not a C coder so its not surprising) and the hardware needs some changes to work properly. The base idea is sound though and I have tested the device several times successfully. I havent been able to wear it all the time because of the stability issues.
    I'm considering maybe switching from cellphone vibration motors to direct current stimulation of the skin. I have a TENS device for an old injury that got me thinking how it could be repurposed for tactile stimulation. Its extremely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
2021-08-24 Added v2 PCB pic
    The V2 PCB is rather nice to look at so I went ahead and added a pic to the front page. It may not have worked, but damn it looks good imo.
